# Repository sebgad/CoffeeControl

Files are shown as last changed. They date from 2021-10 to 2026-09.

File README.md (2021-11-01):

# CoffeeControl :coffee:

This is primarily a temperatur controller for a Rancilio Silvia Espresso machine. Parameters for controller and running the controller can be configured over a web interface. 

**default settings / no connection to wifi possible:** If no wifi is available to connect, a soft-AP (SSID: 'SilviaCoffeeCtrl', no PW)  is setup to control. It can be accessed either by the IP address of the controller or the domain http://coffee.local. In this mode plotting is currently not working (because googleCharts is used). Over the page "settings" the SSID and Password can be setup.

The project is based on an esp32 via the arduino IDE.

## code

### required aduino libaries:
- for Json handling [ArduinoJson](https://arduinojson.org/)
- for Webserver [ESPAsyncWebserver](https://github.com/me-no-dev/ESPAsyncWebServer)
- for Async TCP transfer [AsyncTCP](https://github.com/me-no-dev/AsyncTCP)

In addition there is one file required for individual setup:

"Pt1000.h" for defining individual characteristic of wheatstone bridge:
```c++
#ifndef Pt1000_h
#define Pt1000_h

#define Pt1000_CONV_SQUARE  // define for square interpolation

#include "Arduino.h"

// Define coefficients for linear regression function
// use #define Pt1000_CONV_LINEAR if you want to use the linear interpolation
// variable are only requred if this define is set
const float fPt1000LinCoeffX1 = 433.6520668;
const float fPt1000LinCoeffX0 = 82.01975366;

// Define coefficients for quadratic regression function
// use #define Pt1000_CONV_SQUARE if you want to use the square interpolation
// variable are only requred if this define is set
const float fPt1000SquareCoeffX2 = 295.16714369;
const float fPt1000SquareCoeffX1 = 417.84868016;
const float fPt1000SquareCoeffX0 = 76.91861221;

// Define lookup table for temperature calculation
// use #define Pt1000_CONV_LOOK_UP_TABLE if you want to use the lookup table
// variable are only requred if this define is set
const float arrPt1000LookUpTbl[][2] = {
                                        {-0.21396866840731069, 0.0},
                                        {-0.19826086393703643, 5.0},
                                        {-0.18283911631429636, 10.0},
                                        {-0.16770344877338753, 15.0},
                                        {-0.15282330361877822, 20.0},
                                        {-0.13821466591521075, 25.0},
                                        {-0.12386291635089636, 30.0},
                                        {-0.10976138828633408, 35.0},
                                        {-0.09589652769003139, 40.0},
                                        {-0.08227645893153232, 45.0},
                                        {-0.06888104591949339, 50.0},
                                        {-0.05571158923387528, 55.0},
                                        {-0.0427624663099406, 60.0},
                                        {-0.0300282397238783, 65.0},
                                        {-0.017503649635036495, 70.0},
                                        {-0.00518360659538545, 75.0},
                                        {0.0069431178724726535, 80.0},
                                        {0.01886859632220499, 85.0},
                                        {0.03060996495366849, 90.0},
                                        {0.04216540043842523, 95.0},
                                        {0.05353924250669009, 100.0},
                                        {0.06472982975573649, 105.0},
                                        {0.07575883980844787, 110.0},
                                        {0.08661262418699037, 115.0},
                                        {0.09730088303101485, 120.0},
                                        {0.10782733455505109, 125.0},
                                        {0.11820106425587913, 130.0},
                                        {0.12841994955774214, 135.0},
                                        {0.13848205967873975, 140.0},
                                        {0.1484014359031887, 145.0},
                                        {0.15817588158467566, 150.0},
                                        {0.16780851306788105, 155.0},
                                        {0.17730235788402426, 160.0},
                                        {0.18666535708795248, 165.0},
                                        {0.19589030865119572, 170.0},
                                        {0.20498993006709912, 175.0},
                                        {0.21395711383340363, 180.0},
                                        {0.22280417956398454, 185.0},
                                        {0.23152881217857227, 190.0},
                                        {0.2401335018563869, 195.0},
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
                                      };
#endif
```

## PCB
- The PCB was created via KiCAD [KiCAD](https://www.kicad.org/)
- Rouing was done via the autorouter from freerouting [freerouting](https://github.com/freerouting/freerouting)
- The sorce fiels of the PCB are in *tools/PCB-KiCAD/EspressoV1*
Note:
- The autorouter cannot create a 100% working PCB but is a good start 
- Do not sace the preferenences of the outorouter. Otherweise the routing cannot be redone. See [here](https://github.com/freerouting/freerouting/issues/26#issuecomment-814837891)
- The Design uses an own libary. KiCAD might not be able to find the file initially. 
	- re-Open KiCAD: Do Fixes in "Symbol Editor" and "Footprint Editor":
	- Preferences -> Symbol Libaries|Manage Footprint Libaries : update the path of the esp32 libary
	- close and open KiCAD

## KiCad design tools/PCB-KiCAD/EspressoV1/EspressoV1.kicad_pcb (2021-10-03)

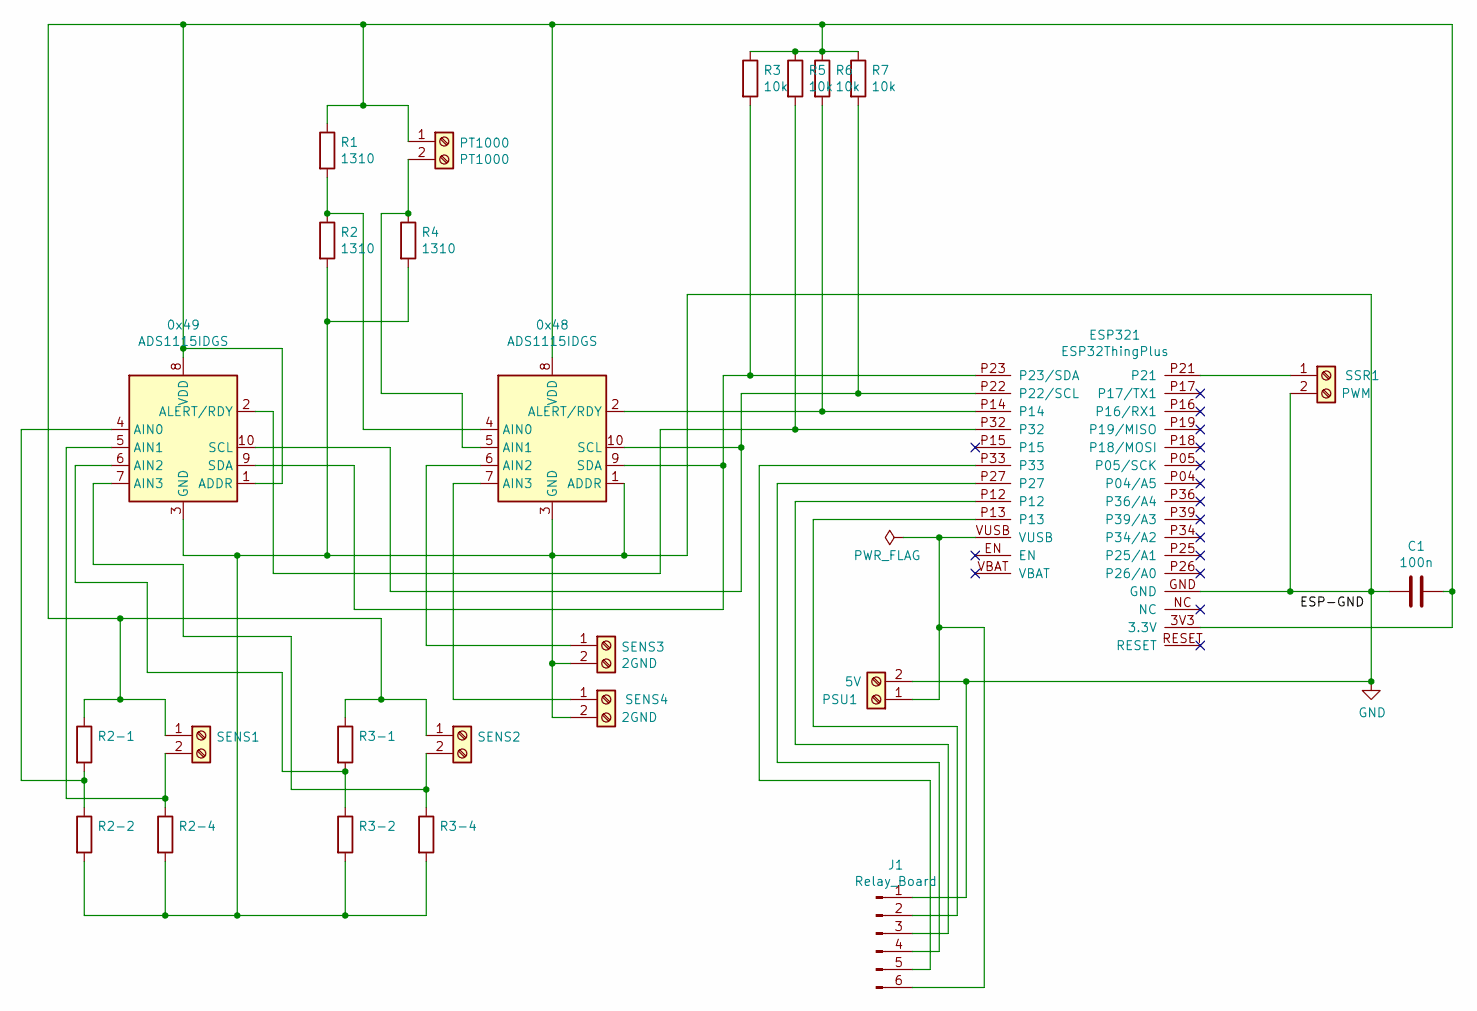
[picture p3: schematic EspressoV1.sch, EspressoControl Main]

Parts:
0x48, 0x49: ADS1115IDGS; ADS1115
C1: 100n; C_Rect_L13.0mm_W5.0mm_P10.00mm_FKS3_FKP3_MKS4
ESP321: ESP32ThingPlus
J1: Relay_Board; PinHeader_1x06_P2.54mm_Vertical
PSU1: 5V; TerminalBlock_Phoenix_MKDS-1,5-2-5.08_1x02_P5.08mm_Horizont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
PT1000: PT1000; TerminalBlock_Phoenix_MKDS-1,5-2-5.08_1x02_P5.08mm_Horizont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
R1, R2, R3-1, R3-2, R3-4, R4: 1310; R_Axial_DIN0207_L6.3mm_D2.5mm_P10.16mm_Horizontal
R2-1, R2-2, R2-4: 0; R_Axial_DIN0207_L6.3mm_D2.5mm_P10.16mm_Horizontal
R3, R5, R6, R7: 10k; R_Axial_DIN0207_L6.3mm_D2.5mm_P10.16mm_Horizontal
SENS1: -; TerminalBlock_Phoenix_MKDS-1,5-2-5.08_1x02_P5.08mm_Horizont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
SENS2: PT1000; TerminalBlock_Phoenix_MKDS-1,5-2-5.08_1x02_P5.08mm_Horizont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
SENS3, SENS4: 2GND; TerminalBlock_Phoenix_MKDS-1,5-2-5.08_1x02_P5.08mm_Horizont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
SSR1: PWM; TerminalBlock_Phoenix_MKDS-1,5-2-5.08_1x02_P5.08mm_Horizont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

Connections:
GND: 0x48.1 (ADDR), 0x48.3 (GND), 0x49.3 (GND), C1.2, ESP321.GND, J1.1, PSU1.2, R2.2, R2-2.2, R2-4.2, R3-2.2, R3-4.2, R4.2, SENS3.2, SENS4.2, SSR1.2
unnamed: 0x48.2 (ALERT/RDY), ESP321.P14, R6.2
unnamed: 0x48.4 (AIN0), R1.2, R2.1
unnamed: 0x48.5 (AIN1), PT1000.2, R4.1
unnamed: 0x48.6 (AIN2), SENS3.1
unnamed: 0x48.7 (AIN3), SENS4.1
unnamed: 0x48.8 (VDD), 0x49.1 (ADDR), 0x49.8 (VDD), C1.1, ESP321.3V3 (3.3V), PT1000.1, R1.1, R2-1.1, R3.1, R3-1.1, R5.1, R6.1, R7.1, SENS1.1, SENS2.1
unnamed: 0x48.9 (SDA), 0x49.9 (SDA), ESP321.P23 (P23/SDA), R3.2
unnamed: 0x48.10 (SCL), 0x49.10 (SCL), ESP321.P22 (P22/SCL), R7.2
unnamed: 0x49.2 (ALERT/RDY), ESP321.P32, R5.2
unnamed: 0x49.4 (AIN0), R2-1.2, R2-2.1
unnamed: 0x49.5 (AIN1), R2-4.1, SENS1.2
unnamed: 0x49.6 (AIN2), R3-1.2, R3-2.1
unnamed: 0x49.7 (AIN3), R3-4.1, SENS2.2
unnamed: ESP321.P12, J1.3
unnamed: ESP321.P13, J1.2
unnamed: ESP321.P21, SSR1.1
unnamed: ESP321.P27, J1.4
unnamed: ESP321.P33, J1.5
unnamed: ESP321.VUSB, J1.6, PSU1.1

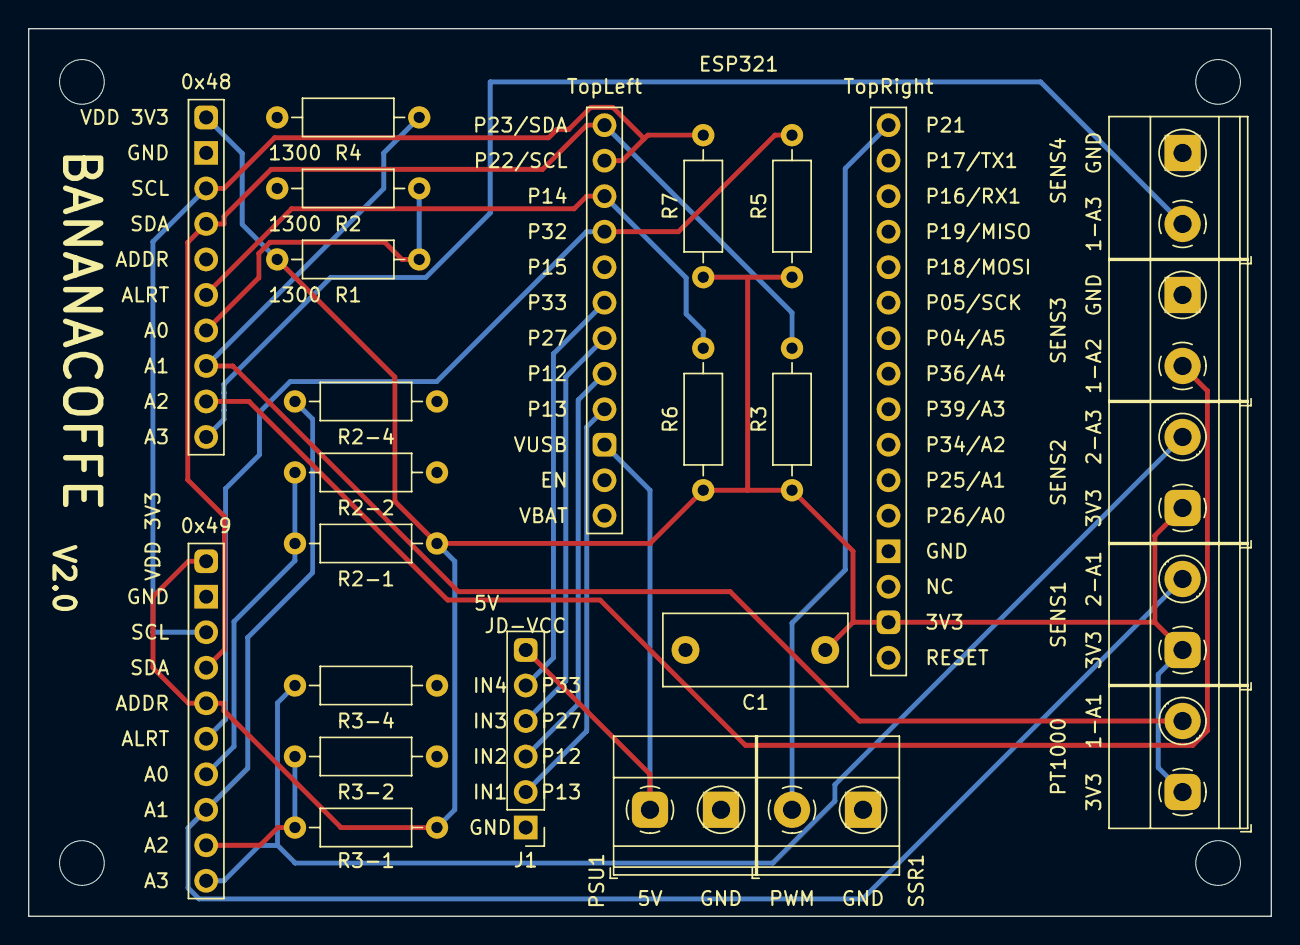
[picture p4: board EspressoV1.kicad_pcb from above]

Board: 2 copper layers, 88.9 x 63.5 mm, 29 parts (0 on the bottom side), 20 nets.

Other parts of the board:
OL: MountingHole_3.2mm_M3
OR: MountingHole_3.2mm_M3
UL: MountingHole_3.2mm_M3
UR: MountingHole_3.2mm_M3

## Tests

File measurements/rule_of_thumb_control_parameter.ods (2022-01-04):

x_min | 0
x_max | 255
y_target | 90 |  |  | °C
y_min | 20 |  |  | °C
Ks | 0,274509803921569 |  |  | °C/1
Tu | 22,9 |  |  | s
Tg | 164,6 |  |  | s
Ziegler/Nichols | PID | PI | P
Kr | 31,4208359326263 | 23,5656269494697 | 26,1840299438553 | 1/°C
Tn | 45,8 | 76,257 |  | s
Tv | 11,45 |  |  | s
Oppelt
Kr | 31,4208359326263 | 20,9472239550842 | 26,1840299438553 | 1/°C
Tn | 45,8 | 68,7 |  | s
Tv | 9,618 |  |  | s
Rosenberg
Kr | 31,5470240287413 | 23,803663585323 | 26,1840299438553 | 1/°C
Tn | 45,8 | 75,57 |  | s
Tv | 10,1777777777778 |  |  | s
Chien/Hornes/Reswick
Kr | 15,7104179663132 | 9,16441048034934 | 7,85520898315658 | 1/°C
Tn | 164,6 | 27,48 |  | s
Tv | 11,45 |  |  | s

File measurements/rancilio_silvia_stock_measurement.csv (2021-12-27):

Measurement File created on Tue Dec 21 08:08:41 2021
Time | Temperature | Heating | TargetPWM
0.4530 | 20.80 | 1 | 255.00
0.9030 | 20.45 | 1 | 255.00
1.3530 | 22.51 | 1 | 255.00
1.8020 | 20.45 | 1 | 255.00
2.2520 | 21.99 | 1 | 255.00
2.7020 | 22.34 | 1 | 255.00
3.1580 | 20.45 | 1 | 255.00
3.6070 | 20.45 | 1 | 255.00
4.0560 | 20.45 | 1 | 255.00
4.5050 | 22.34 | 1 | 255.00
4.9550 | 22.51 | 1 | 255.00
5.4040 | 20.45 | 1 | 255.00
5.8530 | 20.62 | 1 | 255.00
6.3030 | 20.45 | 1 | 255.00
6.7530 | 20.80 | 1 | 255.00
7.2020 | 20.45 | 1 | 255.00
7.6520 | 20.62 | 1 | 255.00
8.1070 | 20.45 | 1 | 255.00
8.5570 | 20.62 | 1 | 255.00
9.0060 | 20.97 | 1 | 255.00
9.4550 | 20.62 | 1 | 255.00
9.9040 | 22.34 | 1 | 255.00
10.3540 | 20.62 | 1 | 255.00
10.8030 | 20.45 | 1 | 255.00
11.2520 | 20.62 | 1 | 255.00
11.7020 | 20.45 | 1 | 255.00
12.1520 | 20.45 | 1 | 255.00
12.6070 | 20.45 | 1 | 255.00
13.1330 | 22.51 | 1 | 255.00
13.5070 | 20.45 | 1 | 255.00
13.9560 | 20.62 | 1 | 255.00
14.4050 | 20.45 | 1 | 255.00
14.8540 | 20.62 | 1 | 255.00
15.3040 | 20.45 | 1 | 255.00
15.7530 | 20.45 | 1 | 255.00
16.2020 | 20.62 | 1 | 255.00
16.6520 | 20.45 | 1 | 255.00
17.1020 | 22.34 | 1 | 255.00
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

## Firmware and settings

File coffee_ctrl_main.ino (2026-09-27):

/*********
 *
 * coffee_ctrl_main
 * A script to control an espresso machine and display measurement values on a webserver of an ESP32
 *
*********/

#include "coffee_ctrl_types.h"
#include <WiFi.h>
#include <ArduinoJson.h>
#include <ESPAsyncWebServer.h>
#include <ESPmDNS.h>
#include <LittleFS.h>
#include "Pt1000.h"
#include "ADS1115.h"
#include "PidCtrl.h"
#include "WifiAccess.h"
#include "AsyncJson.h"
#include "ota.h"
#include <Update.h>
#include <esp_task_wdt.h>
#include <esp32-hal-log.h>

/* File paths for measurement and calibration file */
const char* strMeasFilePath = "/data.csv";
bool bMeasFileLocked = false;
const char* strParamFilePath = "/params.json";
bool bParamFileLocked = false;
const char* strRecentLogFilePath = "/logfile_recent.txt";
const char* strLastLogFilePath = "/logfile_last.txt";
static char bufPrintLog[512];
const char* strUserLogLabel = "USER";

/* Time out status for soft off */
bool bTimeOutReached = false;

/* start time for measurement */
unsigned long iTimeStart = 0;

/* define target PWM */
float fTarPwm;
/* state of the brewing feedforward (exponential decay, see controlHeating) */
float fBrewFf = 0.F;
unsigned long iBrewFfMillis = 0;

/* define configuration struct */
config objConfig;

/* global variabel for WiFi strength */
int iDbmPercentage = 0;

/* Sensor variables */
float fTime = 0.F;
float fTemp = 0.F;

/* bit variable to indicate whether ESP32 has a online connection */
bool bEspOnline = false;
bool bEspMdns = false;

/* configure NTP client */
const char* charNtpServerUrl = "europe.pool.ntp.org";
const long  iGmtOffsetSec = 3600; /* UTC for germany +1h = 3600s */
const int   iDayLightOffsetSec = 3600; /*s Time change in germany 1h = 3600s */

/* Initialize ADS1115 I2C connection */
ADS1115 *objADS1115 = new ADS1115;

/* timer object for ISR */
hw_timer_t * objTimerLong = NULL;

/* define Counter for interrupt handling */
volatile unsigned long iInterruptCntLong = 0;
volatile unsigned long iInterruptCntAlert = 0;
volatile unsigned long pump_relay_last_interrupt_time = 0;
volatile unsigned long iInterruptCntPump = 0;

/* Initialisation of PID controler */
PidCtrl objPid;

/* Definition for critical section port */
portMUX_TYPE objTimerMux = portMUX_INITIALIZER_UNLOCKED;

/* Task intervals in microseconds */
const unsigned long iInterruptLongIntervalMicros = 450000; /*microseconds */

/* Create AsyncWebServer object on port 80 */
AsyncWebServer server(80);

/* Status for function call timing, used in ISR */
volatile struct state iState = {IDLE, IDLE};

int iErrorId = NO_ERROR;

/* timers ============================================================================================================== */
void IRAM_ATTR onAlertRdy(){
  /** Interrupt Service Routine for sensor read outs
   *  Info: IRAM_ATTR stores function in RAM instead of flash memory, faster.
  **/

  /* Define Critical Code section, also needs to be called in Main-Loop */
    portENTER_CRITICAL_ISR(&objTimerMux);
    /* Perform Measurement on interrupt call */
    iState.previous = iState.actual;
    iState.actual |= MEASURE;

    if (iInterruptCntAlert % 3 == 0) {
        /* Only apply control on every third interrupt */
        iState.actual |= PID_CTRL;
    }
    iInterruptCntAlert++;
    portEXIT_CRITICAL_ISR(&objTimerMux);
}

void IRAM_ATTR onPumpRelayChange(){
  /**
   * ISR for changing Pump Relay Status
  */

  portENTER_CRITICAL_ISR(&objTimerMux);

  if ((iState.actual & BREWING_DETECTION) != BREWING_DETECTION)
  {
    iState.previous = iState.actual;
    iState.actual |= BREWING_DETECTION;
    pump_relay_last_interrupt_time = millis();
  }
  portEXIT_CRITICAL_ISR(&objTimerMux);
  iInterruptCntPump++;
}

void IRAM_ATTR onTimerLong(){
  /** ISR triggered by timer alarm. Used for Store Measurement file, LED-Set and DIAG-Function
   *  Info: IRAM_ATTR stores function in RAM instead of flash memory, faster.
  **/

  /* Define Critical Code section, also needs to be called in Main-Loop */
    portENTER_CRITICAL_ISR(&objTimerMux);
      /* Only change Status when idle to measurement running */
      iState.previous = iState.actual;
      if (iInterruptCntLong % 1 == 0) {
        iState.actual |= STORE;
      }

      if (iInterruptCntLong % 3 == 0) {
        /* Only write LED value when interrupt function is called 5 times */
        iState.actual |= LED_CTRL;
      }

      if (iInterruptCntLong % 2 == 0){
        iState.actual |= DIAG;
      }
    portEXIT_CRITICAL_ISR(&objTimerMux);

    /* Interrupt counter */
    iInterruptCntLong++;
}


bool connectWiFi(const int i_total_fail = 3, const int i_timout_attemp = 1000){
  /**
   * Try to connect to WiFi Accesspoint based on the given information in the header file WiFiAccess.h.
   * A defined number of connection is performed.
   * @param
   *    i_timout_attemp:     Total amount of connection attemps
   *    i_waiting_time:   Waiting time between connection attemps
   *
   * @return
   *    b_status:         true if connection is successfull
   */

  bool b_successful = false;

  esp_log_write(ESP_LOG_INFO, strUserLogLabel,  "Device %s try connecting to %s\n", WiFi.macAddress().c_str(),
                objConfig.wifiSSID.c_str());

  int i_run_cnt_fail = 0;
  int i_wifi_status;

  WiFi.mode(WIFI_STA);

  /* Connect to WPA/WPA2 network: */
  WiFi.begin(objConfig.wifiSSID.c_str(), objConfig.wifiPassword.c_str());
  i_wifi_status = WiFi.status();

  while ((i_wifi_status != WL_CONNECTED) && (i_run_cnt_fail<i_total_fail)) {
    /* wait for connection establish */
    vTaskDelay(i_timout_attemp/portTICK_PERIOD_MS);
    i_run_cnt_fail++;
    i_wifi_status = WiFi.status();
    esp_log_write(ESP_LOG_INFO, strUserLogLabel,  "Connection Attemp: %d\n", i_run_cnt_fail);
  }

  if (i_wifi_status == WL_CONNECTED) {
      /* Print ESP32 Local IP Address */
      esp_log_write(ESP_LOG_INFO, strUserLogLabel,  "Connection successful. Local IP: %s\n",
                    WiFi.localIP().toString().c_str());

      /* Signal strength and approximate conversion to percentage */
      int i_dBm = WiFi.RSSI();
      calcWifiStrength(i_dBm);

      esp_log_write(ESP_LOG_INFO, strUserLogLabel,  "Signal strength: %d dB -> %d %%\n", i_dBm, iDbmPercentage);
      b_successful = true;
      WiFi.setAutoReconnect(true);
  } else {
    esp_log_write(ESP_LOG_WARN, strUserLogLabel,  "Connection unsuccessful. WiFi status: %d\n", i_wifi_status);
  }

  return b_successful;
} /* connectWiFi */

void calcWifiStrength(int i_dBm){
  /**
   * calculate the wifi strength from dB to %
   */
  iDbmPercentage = 0;
  if (i_dBm>=-50) {
    iDbmPercentage = 100;
  } else if (i_dBm<=-100) {
    iDbmPercentage = 0;
  } else {
    iDbmPercentage = 2*(i_dBm+100);
  }
}/* calcWifiStrength() */

bool loadConfiguration(){
  /**
   * Load configuration from configuration file
   */

  bool b_success = false;

  if (!bParamFileLocked){
    /* file is not locked by another process ->  save to read or write */
    bParamFileLocked = true;
    File obj_param_file = LittleFS.open(strParamFilePath, "r");
    JsonDocument json_doc;
    DeserializationError error = deserializeJson(json_doc, obj_param_file);

    if ((!obj_param_file) || (error)){
      esp_log_write(ESP_LOG_INFO, strUserLogLabel, "Failed to read file, using default configuration.\n");

      if (!obj_param_file) {
        esp_log_write(ESP_LOG_INFO, strUserLogLabel, "File could not be opened.\n");
      }

      if (error) {
        /*esp_log_write(ESP_LOG_ERROR, strUserLogLabel, "JSON deserializion error: %*c\n", error.c_str()); */
      }
      obj_param_file.close();

      bParamFileLocked = false;
      resetConfiguration(true);
    } else {
      /* file could be read without issues and json document could be interpreted */
      bParamFileLocked = false;
      /* reset configuration struct before writing to get default values */
      resetConfiguration(false);
      bool b_set_default_values = false;

      /* Assign Values from json-File to configuration struct. If Field does not exist in JSON-File write default value to JSON file. */
      (json_doc["Wifi"]["wifiSSID"])?objConfig.wifiSSID = json_doc["Wifi"]["wifiSSID"].as<String>():b_set_default_values = true; /* issue #118 in ArduinoJson */
      (json_doc["Wifi"]["wifiPassword"])?objConfig.wifiPassword = json_doc["Wifi"]["wifiPassword"].as<String>():b_set_default_values = true; /* issue #118 in ArduinoJson */
      (json_doc["PID"]["CtrlTimeFactor"])?objConfig.CtrlTimeFactor = json_doc["PID"]["CtrlTimeFactor"]:b_set_default_values = true;
      (json_doc["PID"]["CtrlPropActivate"])?objConfig.CtrlPropActivate = json_doc["PID"]["CtrlPropActivate"]:b_set_default_values = true;
      (json_doc["PID"]["CtrlPropFactor"])?objConfig.CtrlPropFactor = json_doc["PID"]["CtrlPropFactor"]:b_set_default_values = true;
      (json_doc["PID"]["CtrlIntActivate"])?objConfig.CtrlIntActivate = json_doc["PID"]["CtrlIntActivate"]:b_set_default_values = true;
      (json_doc["PID"]["CtrlIntFactor"])?objConfig.CtrlIntFactor = json_doc["PID"]["CtrlIntFactor"]:b_set_default_values = true;
      (json_doc["PID"]["CtrlDifActivate"])?objConfig.CtrlDifActivate = json_doc["PID"]["CtrlDifActivate"]:b_set_default_values = true;
      (json_doc["PID"]["CtrlDifFactor"])?objConfig.CtrlDifFactor = json_doc["PID"]["CtrlDifFactor"]:b_set_default_values = true;
      (json_doc["PID"]["CtrlTarget"])?objConfig.CtrlTarget = json_doc["PID"]["CtrlTarget"]:b_set_default_values = true;
      (json_doc["PID"]["LowThresholdActivate"])?objConfig.LowThresholdActivate = json_doc["PID"]["LowThresholdActivate"]:b_set_default_values = true;
      (json_doc["PID"]["LowThresholdValue"])?objConfig.LowThresholdValue = json_doc["PID"]["LowThresholdValue"]:b_set_default_values = true;
      (json_doc["PID"]["HighThresholdActivate"])?objConfig.HighThresholdActivate = json_doc["PID"]["HighThresholdActivate"]:b_set_default_values = true;
      (json_doc["PID"]["HighTresholdValue"])?objConfig.HighTresholdValue = json_doc["PID"]["HighTresholdValue"]:b_set_default_values = true;
      (json_doc["PID"]["LowLimitManipulation"])?objConfig.LowLimitManipulation = json_doc["PID"]["LowLimitManipulation"]:b_set_default_values = true;
      (json_doc["PID"]["HighLimitManipulation"])?objConfig.HighLimitManipulation = json_doc["PID"]["HighLimitManipulation"]:b_set_default_values = true;
      /* isNull() instead of truthiness: a deliberate 0 must not be mistaken for a missing key */
      (!json_doc["PID"]["CtrlDifFilterTime"].isNull())?objConfig.CtrlDifFilterTime = json_doc["PID"]["CtrlDifFilterTime"]:b_set_default_values = true;
      (!json_doc["PID"]["BrewFfStart"].isNull())?objConfig.BrewFfStart = json_doc["PID"]["BrewFfStart"]:b_set_default_values = true;
      (!json_doc["PID"]["BrewFfEnd"].isNull())?objConfig.BrewFfEnd = json_doc["PID"]["BrewFfEnd"]:b_set_default_values = true;
      (!json_doc["PID"]["BrewFfTau"].isNull())?objConfig.BrewFfTau = json_doc["PID"]["BrewFfTau"]:b_set_default_values = true;
      (!json_doc["PID"]["BrewFfGain"].isNull())?objConfig.BrewFfGain = json_doc["PID"]["BrewFfGain"]:b_set_default_values = true;
      (json_doc["SSR"]["SsrFreq"])?objConfig.SsrFreq = json_doc["SSR"]["SsrFreq"]:b_set_default_values = true;
      (json_doc["SSR"]["PwmSsrResolution"])?objConfig.PwmSsrResolution = json_doc["SSR"]["PwmSsrResolution"]:b_set_default_values = true;
      (json_doc["LED"]["RwmRgbFreq"])?objConfig.RwmRgbFreq = json_doc["LED"]["RwmRgbFreq"]:b_set_default_values = true;
      (json_doc["LED"]["RwmRgbResolution"])?objConfig.RwmRgbResolution = json_doc["LED"]["RwmRgbResolution"]:b_set_default_values = true;
      (json_doc["LED"]["GainFactorRed"])?objConfig.RwmRgbGainFactorRed = json_doc["LED"]["GainFactorRed"]:b_set_default_values = true;
      (json_doc["LED"]["GainFactorGreen"])?objConfig.RwmRgbGainFactorGreen = json_doc["LED"]["GainFactorGreen"]:b_set_default_values = true;
      (json_doc["LED"]["GainFactorBlue"])?objConfig.RwmRgbGainFactorBlue = json_doc["LED"]["GainFactorBlue"]:b_set_default_values = true;
      (json_doc["LED"]["GainFactorColorRed"])?objConfig.RwmRgbColorRedFactor = json_doc["LED"]["GainFactorColorRed"]:b_set_default_values = true;
      (json_doc["LED"]["GainFactorColorGreen"])?objConfig.RwmRgbColorGreenFactor = json_doc["LED"]["GainFactorColorGreen"]:b_set_default_values = true;
      (json_doc["LED"]["GainFactorColorBlue"])?objConfig.RwmRgbColorBlueFactor = json_doc["LED"]["GainFactorColorBlue"]:b_set_default_values = true;
      (json_doc["LED"]["GainFactorColorOrange"])?objConfig.RwmRgbColorOrangeFactor = json_doc["LED"]["GainFactorColorOrange"]:b_set_default_values = true;
      (json_doc["LED"]["GainFactorColorPurple"])?objConfig.RwmRgbColorPurpleFactor = json_doc["LED"]["GainFactorColorPurple"]:b_set_default_values = true;
      (json_doc["LED"]["GainFactorColorWhite"])?objConfig.RwmRgbColorWhiteFactor = json_doc["LED"]["GainFactorColorWhite"]:b_set_default_values = true;
      (json_doc["Signal"]["SigFilterActive"])?objConfig.SigFilterActive = json_doc["Signal"]["SigFilterActive"]:b_set_default_values = true;
      (json_doc["System"]["TimeToStandby"])?objConfig.TimeToStandby = json_doc["System"]["TimeToStandby"]:b_set_default_values = true;

      if (b_set_default_values){
        /* default values are set to Json object -> write it back to file. */
        if (!saveConfiguration()){
          esp_log_write(ESP_LOG_INFO, strUserLogLabel, "Cannot write back to JSON file.\n");
        }
      }
  }
    b_success = true;
  } else {
    b_success = false;
  }
  return b_success;
}

bool saveConfiguration(){
  /**
   * Save configuration to configuration file
   */

  bool b_success = false;
  JsonDocument json_doc;

  json_doc["Wifi"]["wifiSSID"] = objConfig.wifiSSID;
  json_doc["Wifi"]["wifiPassword"] = objConfig.wifiPassword;
  json_doc["PID"]["CtrlTimeFactor"] = objConfig.CtrlTimeFactor;
  json_doc["PID"]["CtrlPropActivate"] = objConfig.CtrlPropActivate;
  json_doc["PID"]["CtrlPropFactor"] = objConfig.CtrlPropFactor;
  json_doc["PID"]["CtrlIntActivate"] = objConfig.CtrlIntActivate;
  json_doc["PID"]["CtrlIntFactor"] = objConfig.CtrlIntFactor;
  json_doc["PID"]["CtrlDifActivate"] = objConfig.CtrlDifActivate;
  json_doc["PID"]["CtrlDifFactor"] = objConfig.CtrlDifFactor;
  json_doc["PID"]["CtrlTarget"] = objConfig.CtrlTarget;
  json_doc["PID"]["LowThresholdActivate"] = objConfig.LowThresholdActivate;
  json_doc["PID"]["LowThresholdValue"] = objConfig.LowThresholdValue;
  json_doc["PID"]["HighThresholdActivate"] = objConfig.HighThresholdActivate;
  json_doc["PID"]["HighTresholdValue"] = objConfig.HighTresholdValue;
  json_doc["PID"]["LowLimitManipulation"] = objConfig.LowLimitManipulation;
  json_doc["PID"]["HighLimitManipulation"] = objConfig.HighLimitManipulation;
  json_doc["PID"]["CtrlDifFilterTime"] = objConfig.CtrlDifFilterTime;
  json_doc["PID"]["BrewFfStart"] = objConfig.BrewFfStart;
  json_doc["PID"]["BrewFfEnd"] = objConfig.BrewFfEnd;
  json_doc["PID"]["BrewFfTau"] = objConfig.BrewFfTau;
  json_doc["PID"]["BrewFfGain"] = objConfig.BrewFfGain;
  json_doc["SSR"]["SsrFreq"]  = objConfig.SsrFreq;
  json_doc["SSR"]["PwmSsrResolution"]  = objConfig.PwmSsrResolution;
  json_doc["LED"]["RwmRgbFreq"] = objConfig.RwmRgbFreq;
  json_doc["LED"]["RwmRgbResolution"] = objConfig.RwmRgbResolution;
  json_doc["LED"]["GainFactorRed"] = objConfig.RwmRgbGainFactorRed;
  json_doc["LED"]["GainFactorGreen"] = objConfig.RwmRgbGainFactorGreen;
  json_doc["LED"]["GainFactorBlue"] = objConfig.RwmRgbGainFactorBlue;
  json_doc["LED"]["GainFactorColorRed"] = objConfig.RwmRgbColorRedFactor;
  json_doc["LED"]["GainFactorColorGreen"] = objConfig.RwmRgbColorGreenFactor;
  json_doc["LED"]["GainFactorColorBlue"] = objConfig.RwmRgbColorBlueFactor;
  json_doc["LED"]["GainFactorColorOrange"] = objConfig.RwmRgbColorOrangeFactor;
  json_doc["LED"]["GainFactorColorPurple"] = objConfig.RwmRgbColorPurpleFactor;
  json_doc["LED"]["GainFactorColorWhite"] = objConfig.RwmRgbColorWhiteFactor;
  json_doc["Signal"]["SigFilterActive"] = objConfig.SigFilterActive;
  json_doc["System"]["TimeToStandby"] = objConfig.TimeToStandby;

  if (!bParamFileLocked){
    bParamFileLocked = true;
    File obj_param_file = LittleFS.open(strParamFilePath, "w");

    if (serializeJsonPretty(json_doc, obj_param_file) == 0) {
      esp_log_write(ESP_LOG_INFO, strUserLogLabel, "Failed to write configuration to file\n");
    }
    else{
      esp_log_write(ESP_LOG_INFO, strUserLogLabel, "Configuration file updated successfully\n");
      b_success = true;
    }
    obj_param_file.close();
    bParamFileLocked = false;
  } else {
    b_success = false;
  }
  return b_success;
}
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
void loop(){
  /* Reset watchdog if loop is entered */
  esp_task_wdt_reset();

  /* Check for brewing status when debouncing counter is elapsed */
  if (((iState.actual & BREWING_DETECTION) == BREWING_DETECTION) && (millis() - pump_relay_last_interrupt_time > 200L))
  {
    /* Set State for activating deactivating brewing process */
    portENTER_CRITICAL_ISR(&objTimerMux);
      iState.previous = iState.actual;
      if (digitalRead(P_PUMP_RELAY) == HIGH)
      {
        iState.actual |= BREWING;
      } else {
        iState.actual &= ~BREWING;
      }
    portEXIT_CRITICAL_ISR(&objTimerMux);
    iState.actual &= ~BREWING_DETECTION;
  }

  if ((iState.actual & CONFIG_UPDATE) == CONFIG_UPDATE) {
    /* New parameters were stored via /paramUpdate, put them into effect */
    configPID();
    configLED();

    if(objConfig.SigFilterActive){
      objADS1115->activateFilter();
    } else {
      objADS1115->deactivateFilter();
    }

    /* the integrator content belongs to the previous coefficients, start clean */
    objPid.reset();

    portENTER_CRITICAL_ISR(&objTimerMux);
      iState.previous = iState.actual;
      iState.actual &= ~CONFIG_UPDATE;
    portEXIT_CRITICAL_ISR(&objTimerMux);
  }

  if ((iState.actual & MEASURE) == MEASURE) {
    fTime = (float)(millis() - iTimeStart) / 1000.0;
    /* get physical value of sensor */
    fTemp = objADS1115->getPhysVal();

    portENTER_CRITICAL_ISR(&objTimerMux);
      iState.previous = iState.actual;
      iState.actual &= ~MEASURE;
    portEXIT_CRITICAL_ISR(&objTimerMux);
  }

  if ((iState.actual & PID_CTRL) == PID_CTRL) {
    /* Call heating control function */
    controlHeating();

    portENTER_CRITICAL_ISR(&objTimerMux);
      iState.previous = iState.actual;
      iState.actual &= ~PID_CTRL;
    portEXIT_CRITICAL_ISR(&objTimerMux);
  }

  if ((iState.actual & LED_CTRL) == LED_CTRL) {
    /* Control LED color */
    if(iErrorId > NO_ERROR){
      setColor(LED_COLOR_PURPLE, false);
    } else if ((iState.actual & BREWING) == BREWING) {
      /* Brew process active */
      setColor(LED_COLOR_RED, true);
    } else if (fTemp < objConfig.CtrlTarget - 1.0) {
      /* Heat up signal */
      setColor(LED_COLOR_ORANGE, true);
    } else if (fTemp > objConfig.CtrlTarget + 1.0){
      /* Cool down signal */
      setColor(LED_COLOR_BLUE, true);
    } else {
      /* temperature in range signal */
      setColor(LED_COLOR_GREEN, true);
    }

    portENTER_CRITICAL_ISR(&objTimerMux);
      iState.previous = iState.actual;
      iState.actual &= ~LED_CTRL;
    portEXIT_CRITICAL_ISR(&objTimerMux);
  }

  if ((iState.actual & STORE) == STORE) {
    /* Write values to measurement file */
    bool b_result_meas_write;
    b_result_meas_write = writeMeasFile();
    if (b_result_meas_write){
      portENTER_CRITICAL_ISR(&objTimerMux);
        iState.previous = iState.actual;
        iState.actual &= ~STORE;
      portEXIT_CRITICAL_ISR(&objTimerMux);

    }
  }

  if ((millis() >= objConfig.TimeToStandby * 1000) && (bTimeOutReached == false)) {
    /* check whether timeout is reached, PWM will be deactivated. */
    bTimeOutReached = true;
    esp_log_write(ESP_LOG_WARN, strUserLogLabel, "Timeout reached -> machine going into sleep\n");
  }

  /* Diagnosis functionality */
  if ((iState.actual & DIAG) == DIAG){
    /* Error: Temperature Range unplausible */
    if (fTemp < 10.F){
      /* Sensor range is not valid */
      iErrorId |= TEMP_OUT_RANGE;
      esp_log_write(ESP_LOG_INFO, strUserLogLabel, "ERROR: Temperature range unplausible. Measured Value: %.2f C.\n", fTemp);
    } else {
      iErrorId &= ~TEMP_OUT_RANGE;
    }

    /* Error: Internal reset of ADS */
    if (objADS1115->getOpMode()==ADS1115_MODE_SINGLESHOT){
      iErrorId |= MEAS_DEV_RESET;
      esp_log_write(ESP_LOG_INFO, strUserLogLabel, "ERROR: Conversion mode changed to single shot (default) during runtime.\n");
    } else {
      iErrorId &= ~MEAS_DEV_RESET;
    }

    if ((WiFi.status() != WL_CONNECTED) && (WiFi.getMode() == WIFI_MODE_STA)){
      iErrorId |= WIFI_DISCONNECT;
      esp_log_write(ESP_LOG_INFO, strUserLogLabel, "ERROR: Wifi disconnected.\n");
    } else {
      iErrorId &= ~WIFI_DISCONNECT;
    }

    /* try error handling */
    if (iErrorId > NO_ERROR){
      if (iErrorId == WIFI_DISCONNECT) {
        server.end();
        server.begin();
      }
    }
    portENTER_CRITICAL_ISR(&objTimerMux);
      iState.actual &= ~DIAG;
    portEXIT_CRITICAL_ISR(&objTimerMux);
  }
}/* loop */

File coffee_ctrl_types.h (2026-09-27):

/**
 * All Types for coffee_ctrl_main are saved here
*/

#define LOG_LEVEL ESP_LOG_VERBOSE

/* PIN definitions */
#define P_PUMP_RELAY 17

/* I2C pins */
#define SDA_0 23
#define SCL_0 22
#define CONV_RDY_PIN 14

/* PWM defines */
#define P_SSR_PWM 21
#define P_RED_LED_PWM 13
#define P_GRN_LED_PWM 27
#define P_BLU_LED_PWM 12
#define P_STAT_LED 33 /* green status LED */

/* File system definitions */
#define FORMAT_SPIFFS_IF_FAILED true

/* define timer related channels for PWM signals */
#define RwmRedChannel 13 /*  PWM channel. There are 16 channels from 0 to 15. Channel 13 is now Red-LED */
#define RwmGrnChannel 14 /*  PWM channel. There are 16 channels from 0 to 15. Channel 14 is now Green-LED */
#define RwmBluChannel 15 /*  PWM channel. There are 16 channels from 0 to 15. Channel 15 is now Blue-LED */
#define PwmSsrChannel 0  /*  PWM channel. There are 16 channels from 0 to 15. Channel 0 is now SSR-Controll */

#define WDT_Timeout 75 /* WatchDog Timeout in seconds */

/* config structure for online calibration */
struct config {
  String wifiSSID;
  String wifiPassword;
  float CtrlTarget;
  bool CtrlTimeFactor;
  bool CtrlPropActivate;
  float CtrlPropFactor;
  bool CtrlIntActivate;
  float CtrlIntFactor;
  bool CtrlDifActivate;
  float CtrlDifFactor;
  float CtrlDifFilterTime;
  bool LowThresholdActivate;
  float LowThresholdValue;
  bool HighThresholdActivate;
  float HighTresholdValue;
  float LowLimitManipulation;
  float HighLimitManipulation;
  float BrewFfStart;
  float BrewFfEnd;
  float BrewFfTau;
  float BrewFfGain;
  uint32_t SsrFreq;
  uint32_t PwmSsrResolution;
  uint32_t RwmRgbFreq;
  uint32_t RwmRgbResolution;
  float RwmRgbGainFactorRed;
  float RwmRgbGainFactorGreen;
  float RwmRgbGainFactorBlue;
  float RwmRgbColorRedFactor;
  float RwmRgbColorGreenFactor;
  float RwmRgbColorBlueFactor;
  float RwmRgbColorOrangeFactor;
  float RwmRgbColorPurpleFactor;
  float RwmRgbColorWhiteFactor;
  bool SigFilterActive;
  uint32_t TimeToStandby;
};

enum eState{
  IDLE      = (1u << 0),
  MEASURE   = (1u << 1),
  PID_CTRL  = (1u << 2),
  STORE     = (1u << 3),
  DIAG      = (1u << 4),
  LED_CTRL  = (1u << 5),
  BREWING_DETECTION = (1 << 6),
  BREWING   = (1u << 7),
  CONFIG_UPDATE = (1u << 8)
};

enum eError{
  NO_ERROR          = (1u << 0),
  TEMP_OUT_RANGE    = (1u << 1),
  MEAS_DEV_RESET    = (1u << 2),
  WIFI_DISCONNECT   = (1u << 3),
  };

enum eLEDColor{
  LED_COLOR_RED,
  LED_COLOR_GREEN,
  LED_COLOR_BLUE,
  LED_COLOR_ORANGE,
  LED_COLOR_PURPLE,
  LED_COLOR_WHITE
};

struct state{
  unsigned int previous;
  unsigned int actual;
};

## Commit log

2021-04-29 add timer and ISR based on https://techtutorialsx.com/2017/10/07/esp32-arduino-timer-interrupts/
2021-05-13 used pin 6 as slow "pwm"like and pin 3 as normal pwm
2021-05-13 added shortcut to gitignore so i dont stage by mistake
2021-05-13 correct pwm usage
2021-05-22 add three timers, still bugfixing timer 3 (measurement stream)
    [coffee_ctrl_main.ino]
2021-05-22 fixed timer3 issue
2021-05-24 sensor read out, pid control and measurement write depend now on one timer
2021-05-30 change timer settings, implement status variables, minor changes on setup
2021-06-02 change bit shifting functionality and add missing register settings
    [ADS1115.cpp, coffee_ctrl_main.ino]
2021-06-03 add missing functionalities, add comments
    [ADS1115.cpp, coffee_ctrl_main.ino]
2021-06-10 setup temp sensor
2021-06-12 initial iteration of PCB. PCB created with KiCAD.
    [EspressoV1-B_Cu.gbl, EspressoV1-B_Mask.gbs, EspressoV1-B_Paste.gbp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]
2021-06-12 added info about the PCB
2021-06-13 PT1000 lookup table; with 7 support points
    [PT1000_lookup_table.xlsx]
2021-06-14 add physical conversion table, fix integer problem
    [ADS1115.cpp, coffee_ctrl_main.ino]
2021-06-14 bugfix i2c func
2021-06-15 fix bitread and write in ADS1115 lib
    [ADS1115.cpp, coffee_ctrl_main.ino]
2021-06-17 fix issue in writeBit and rename function
    [ADS1115.cpp, coffee_ctrl_main.ino]
2021-06-19 adapt calculation for Resistor R1,R2,R4 from 1310Ohm to 1298Ohm
    [PT1000_lookup_table.xlsx]
2021-06-20 implement csv parsing in webserver to read out actual sensor values
2021-06-20 added PID and some comments
2021-06-21 added 1310 ohm calibration; fixt Pin typo
    [coffee_ctrl_main.ino]
2021-06-21 1310 ohm setup
    [PT1000_lookup_table.xlsx]
2021-06-26 get interpolation values for .h file
    [PT_1000_tabelle.csv]
2021-06-26 read voltage in V
2021-06-29 change pwm chart
2021-08-27 add pid parameter handling
2021-08-27 implement ArduinoJson for parameter handling
    [test.csv]
2021-09-01 add JsonLib
    [test.csv]
2021-09-10 adapted PID lib: fixed controller calculation; other coefficients; added OnOffThresholds
2021-09-12 extend online calibrations and functionality to up and download file
2021-09-14 split setup function, bugfix graphs.html
    [coffee_ctrl_main.ino]
2021-10-03 PCB V2
    [EspressoV1.dsn, EspressoV1.kicad_pcb, EspressoV1.sch]
2021-10-03 correct resistor value
    [EspressoV1.kicad_pcb]
2021-11-01 remove include to WifiAccess.h file, bugfixes
    [coffee_ctrl_main.ino]
2021-12-23 change pid controler, add ota functionality
2021-12-23 change coefficient names of PID controller, implement time factor switch for coefficients
2021-12-27 add raw measurement data
    [rancilio_silvia_stock_measurement.csv]
2021-12-28 added RGB LED for pin 13, 12 and 27 and on off pid
2021-12-29 LED write call every 2.5s for debouncing. Change orange to purple
2021-12-30 add antiwindup, add control parameter ods file
    [rule_of_thumb_control_parameter.ods]
2021-12-31 increase sensitivity of ADS1115 to +-0.256V, minor changes
    [rule_of_thumb_control_parameter.ods]
2022-01-01 add conversion monitoring if sensor values are freezing, minor changes
2022-01-01 bugfix sensor diagnosis
2022-01-01 temporary disable diagnosis function. Need to analyze bug.
    [ADS1115.cpp, coffee_ctrl_main.ino]
2022-01-04 added missing config parameters and made them changeable
    [coffee_ctrl_main.ino]
2022-01-06 change JSON structure and settings, remove channels from settings, led color change
2022-01-07 implement signal filter, changed setup call order, minor fixes in pyhton scripts
    [ADS1115.cpp, coffee_ctrl_main.ino]
2022-01-14 remove variable buffer size, add savitzky golay filter for odd buffer size
2022-01-15 change settings button layout
2022-01-16 adapt RGB LED brightness
2022-01-16 measurement of step response and py file to plot
    [20220105_TS_step_17_pwm_1_of_9.csv, 20220105_TS_step_17_pwm_2_of_9.csv, 20220105_TS_step_17_pwm_3_of_9.csv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]
2022-01-16 added diagnosis for when the sensor is stuck and had 10 times the same value
    [ADS1115.cpp, coffee_ctrl_main.ino]
2022-01-16 adapt LED setColor()
2022-01-16 bugfix error LED status
2022-01-19 bugfix LED issue
2022-01-22 rework of diagnosis; not use min==max anymore but check for changed values
    rename of misleading variable name
    [ADS1115.cpp]
2022-01-22 bugfix initializing buffer in ADS1115.cpp, updating all *.html, minor bugfixes, optimize webserver
    [ADS1115.cpp, coffee_ctrl_main.ino]
2022-01-22 bugfix merge conflict :-)
    [ADS1115.cpp]
2022-01-22 bugfix esp restart request over webserver, adapt JSON document size
    [coffee_ctrl_main.ino]
2022-01-23 redirect fix when uploading files
    [coffee_ctrl_main.ino]
2022-01-23 temporary bugfix interrrupt call
    [coffee_ctrl_main.ino]
2022-01-24 bugfix filter settings, setting filter size to 11, comment fileblock method to check repsonsiveness of webserver
    [ADS1115.cpp, coffee_ctrl_main.ino]
2022-02-04 change i2c in ads1015
2022-02-06 fix i2c timing issue
    [coffee_ctrl_main.ino]
2022-02-07 add ota.h and failsafe request
    [coffee_ctrl_main.ino]
2022-02-08 change filter size
2022-02-13 combine all csv to one combined csv
    [20220105_TS_step_17_pwm_combined.csv]
2022-02-27 show WiFi strength in index.html; better filtering and filter debugging.
2022-02-27 bugfix buffer print, change readOut WifiSignal
    [coffee_ctrl_main.ino]
2022-03-03 cleanup and read the register without changing the filter buffer at the end of setup()
2022-03-16 bugfix diagnosis loop ESP_OK
    [coffee_ctrl_main.ino]
2022-03-27 increase watchdog timeout, to cover time at reset. turn led to purple when ADS needs to be reconfigured
    [coffee_ctrl_main.ino]
2023-06-04 change timeout in i2c, operating range
2023-06-08 removed false -positive detection of frozen value for temperatures below 35°C
2023-06-24 bugfix iState check
    [EspressoV1-B_Cu.gbl, EspressoV1-B_Mask.gbs, EspressoV1-B_Paste.gbp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]
2023-06-24 bugfix LED-Ctrl, extend timeout in I2C communication
    [ADS1115.cpp, coffee_ctrl_main.ino]
2023-06-24 add wifi reconnect, change i2c clock speed, bugfix diagnosis
    [ADS1115.cpp, coffee_ctrl_main.ino]
2024-03-29 add serial print output also to UART
2024-05-20 add PID object for brewing activated
2024-06-02 add target temperature to chart, optimize isr for brew detection
2024-07-21 add reset function in PID controller, add struct for status
    [coffee_ctrl_main.ino, coffee_ctrl_types.h]
2026-09-27 Add brewing feedforward and fix derivative handling in PidCtrl
    Changes made while optimising the PID coefficients against measured step
    responses, plus the defects that work uncovered.
    PidCtrl:
    - initialise _fLastControlDev/_fErrDiff in the constructor. They were
    indeterminate, which only mattered once the differential part was enabled.
    - suppress the derivative on the first cycle after start or reset() rather
    than differencing against a placeholder zero.
    - guard the derivative against f_delta_sec == 0. That happens whenever
    compute() follows reset() within the same millisecond, and produced a NaN
    that passed every limit check and reached ledcWrite().
    - add a configurable low pass o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
    [coffee_ctrl_main.ino, coffee_ctrl_types.h]
